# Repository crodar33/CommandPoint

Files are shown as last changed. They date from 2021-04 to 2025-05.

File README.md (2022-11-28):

# Code and shecme for control inverter
Scheme based on ESP8266 for pool data from BSM of the battery with **daly smart bms**
and provide battery data to **SOFAR HYBRID** inverter **HYD6000-ES**

They not compatible to each to other, so I need to make middle man for it work together.

In current implementation it can:

  * pull data from battery by RS485, UART
  * put data to the inverter by CAN and inner inverter protocol
  * show battery state by HTTP
  * show battery errors

Used ESP8266, MCP2515, MAX485 and nodeMCU, code writed on LUA
Build nodemcu with **I2C_MASTER_GPIO16_ENABLE** and without **I2C_MASTER_OLD_VERSION**
LUA_USE_MODULES_SOFTUART
LUA_USE_MODULES_STRUCT
LUA_USE_MODULES_U8G2

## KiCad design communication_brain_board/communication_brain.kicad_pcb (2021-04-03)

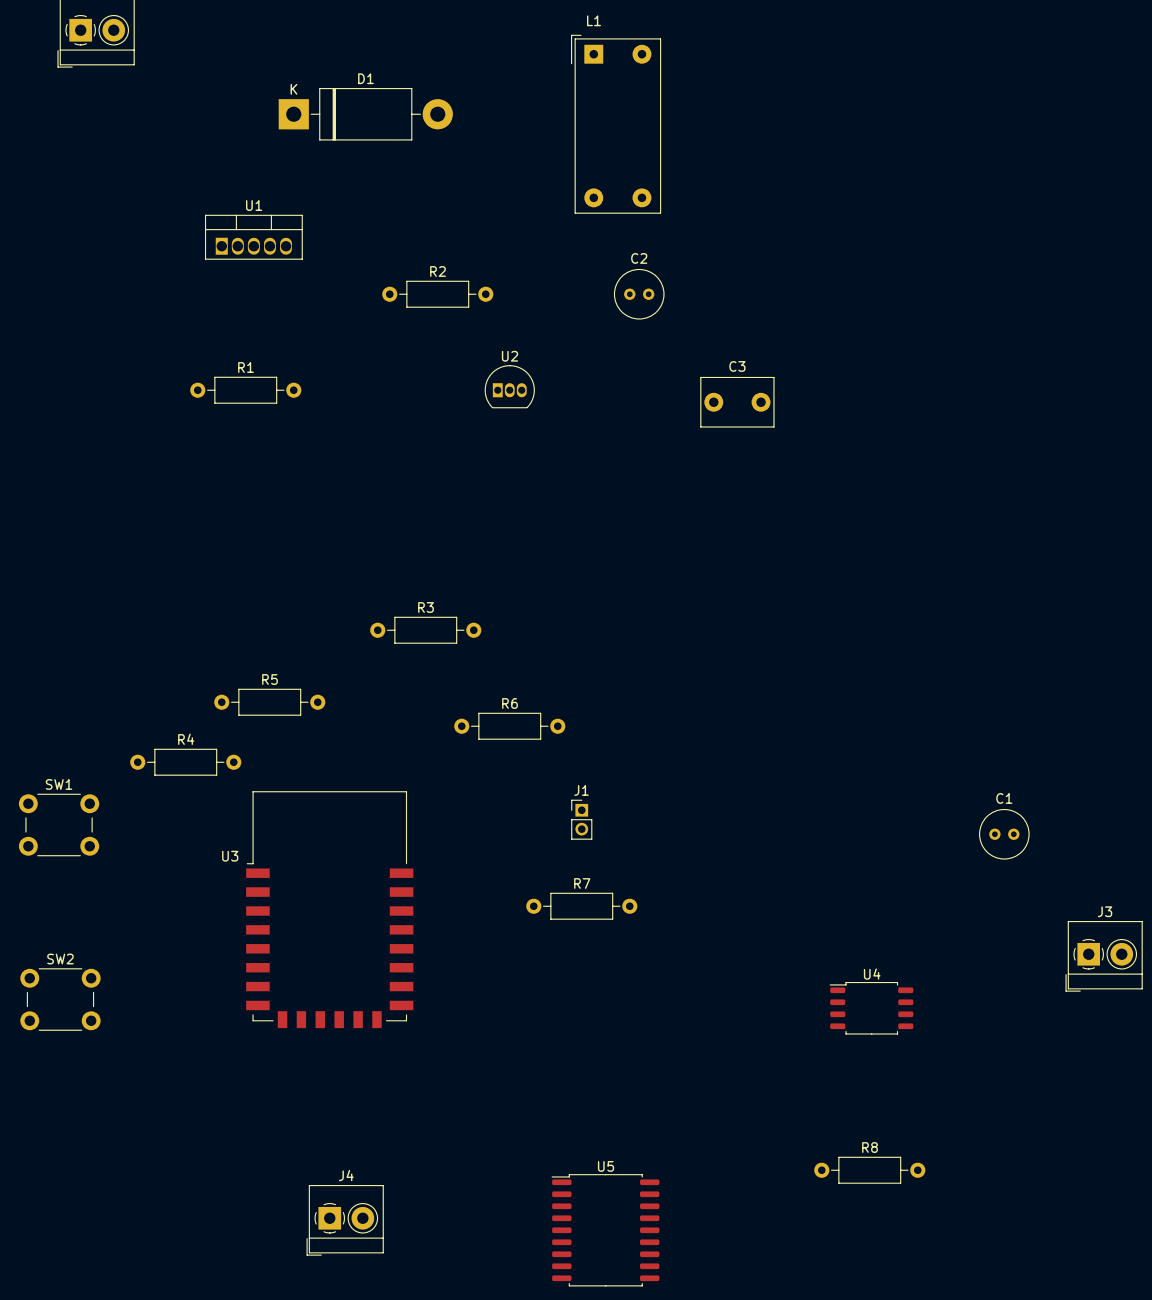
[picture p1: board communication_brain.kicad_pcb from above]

Board: 2 copper layers, 24 parts (0 on the bottom side), 23 nets, no tracks yet.

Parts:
C1: 100mF; C_Radial_D5.0mm_H5.0mm_P2.00mm
C2: 1000mF; C_Radial_D5.0mm_H5.0mm_P2.00mm
C3: 0.1mF; C_Disc_D7.5mm_W5.0mm_P5.00mm
D1: 1N5822; D_DO-201AD_P15.24mm_Horizontal
J1: UART; PinHeader_1x02_P2.00mm_Vertical
J2: Batt; TerminalBlock_4Ucon_1x02_P3.50mm_Horizontal
J3: RS485; TerminalBlock_4Ucon_1x02_P3.50mm_Horizontal
J4: CAN; TerminalBlock_4Ucon_1x02_P3.50mm_Horizontal
L1: 100mH; Choke_Schaffner_RN202-04-8.8x18.2mm
R1: 5.6k; R_Axial_DIN0207_L6.3mm_D2.5mm_P10.16mm_Horizontal
R2: 1.8k; R_Axial_DIN0207_L6.3mm_D2.5mm_P10.16mm_Horizontal
R3, R4, R5, R6, R7, R8: 10k; R_Axial_DIN0207_L6.3mm_D2.5mm_P10.16mm_Horizontal
SW1: Reset; SW_PUSH_6mm_H5mm
SW2: Programm; SW_PUSH_6mm_H5mm
U1: LM2576HVT-ADJ; TO-220-5_Vertical
U2: L78L33_TO92; TO-92_Inline
U3: ESP-12E
U4: MAX485E; SOIC-8_5.23x5.23mm_P1.27mm
U5: MCP2515-xSO; SOIC-18W_7.5x11.6mm_P1.27mm

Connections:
+3V3: C3.1, R3.1, R4.1, R5.1, R6.1, U2.1, U3.8, U4.8, U5.9, U5.18
+5V: C2.1, L1.2, R2.1, U2.3
+BATT: C1.1, J2.2, U1.1
-BATT: C1.2, C2.2, C3.2, D1.2, J2.1, R1.2, R7.2, R8.2, SW1.1, SW1.2, SW2.1, SW2.2, U1.3, U1.5, U2.2, U3.15, U4.5
/CS: U3.9, U5.16
/RXD: J1.1, U3.21
/SCK: U3.14, U5.13
/SI: U3.13, U5.14
/SO: U3.10, U5.15
/TXD: J1.2, U3.22
unnamed: D1.1, L1.1, U1.2
unnamed: J3.1, U4.7
unnamed: J3.2, U4.6
unnamed: J4.1, U5.2
unnamed: J4.2, U5.1
unnamed: R1.1, R2.2, U1.4
unnamed: R3.2, U3.3
unnamed: R4.2, U3.1
unnamed: R5.2, U3.18
unnamed: R6.2, U3.17, U4.1
unnamed: R7.1, U3.16
unnamed: R8.1, U3.6, U4.2, U4.3
unnamed: U3.7, U4.4

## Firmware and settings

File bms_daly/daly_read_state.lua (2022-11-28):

return function(battery, sUart, RW_pin)

    local callback = function(data)
        if not chechCRC(data) then
            print("bad CRC 0x98")
            print("Response: ", dataToString(data)) 
            return
        end
        if (struct.unpack("B", data, 2)~=battery.address) then
            return
        end
        battery.last_update = tmr.time()
        --print("Got state: ", dataToString(data)) 
        battery.state[0] = struct.unpack("b", data, 5+0)
        battery.state[1] = struct.unpack("b", data, 5+1)
        battery.state[2] = struct.unpack("b", data, 5+2)
        battery.state[3] = struct.unpack("b", data, 5+3)
        battery.state[4] = struct.unpack("b", data, 5+4)
        battery.state[5] = struct.unpack("b", data, 5+5)
        battery.state[6] = struct.unpack("b", data, 5+6)
        battery.state[7] = struct.unpack("b", data, 5+7)
    end
  
    print("request state")
    --request new data
    local sendData = struct.pack(">BBBBBBBBBBBBB", 0xA5, 0x40, 0x98, 0x08, 0, 0, 0, 0, 0, 0, 0, 0, 0x85)    
    --set callback on what we waiting
    --print("Requested: ", dataToString(sendData))
    sUart:on("data", 13, callback)
    --send data
    gpio.write(RW_pin, gpio.HIGH)
    sUart:write(sendData)
    gpio.write(RW_pin, gpio.LOW)

end

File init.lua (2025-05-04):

print("===========================================")
print("STARTING")
print("===========================================")
wifi.setmode(wifi.STATION)
local station_cfg= require("wifi_config")
wifi.sta.config(station_cfg)

function dataToString(data)
    local result = ''
    for i=1, #data do
        local val = struct.unpack(">B", data, i)
        result = result .. " 0X" .. string.format("%02X", val)
    end
    return result
end
 
ntpTime = 0
local modbus_proxy = nil
local wifiGotIpEvent = function(T)
    print("My IP: " .. T.IP)
    --watch for time
--[[
    timerNtp = tmr.create()
    timerNtp:register(10000, tmr.ALARM_AUTO, function()
        sntp.sync('192.168.42.1', 
            function(sec, usec, server, info) 
                print("ntp time " .. sec) 
                ntpTime = sec
            end,
            function()
                ntpTime = ntpTime + 10
            end
        )
    end)
    timerNtp:start()
]]
    --modbus_proxy = dofile("tcp_modbus.lua");
end

local wifiConnectEvent = function(T)
    print("Connection to AP("..T.SSID..") established!")
    print("Waiting for IP address...")
    if disconnect_ct ~= nil then disconnect_ct = nil end
end
wifiDisconnectEvent = function(T)
    if modbus_proxy ~= nil then
        modbus_proxy:close()
        modbus_proxy = nil
    end
    if T.reason == wifi.eventmon.reason.ASSOC_LEAVE then
        --the station has disassociated from a previously connected AP
        return
    end
    -- total_tries: how many times the station will attempt to connect to the AP. Should consider AP reboot duration.
    local total_tries = 75
    print("\nWiFi connection to AP("..T.SSID..") has failed!")

    --There are many possible disconnect reasons, the following iterates through
    --the list and returns the string corresponding to the disconnect reason.
    for key,val in pairs(wifi.eventmon.reason) do
        if val == T.reason then
            print("Disconnect reason: "..val.."("..key..")")
            --node.restart() 
            break
        end
    end

    if disconnect_ct == nil then
        disconnect_ct = 1
    else
        disconnect_ct = disconnect_ct + 1
    end
    if disconnect_ct < total_tries then
        print("Retrying connection...(attempt "..(disconnect_ct+1).." of "..total_tries..")")
    else
        wifi.sta.disconnect()
        print("Aborting connection to AP!")
        disconnect_ct = nil
        node.restart() 
    end
end
-- Register WiFi Station event callbacks
wifi.eventmon.register(wifi.eventmon.STA_CONNECTED, wifiConnectEvent)
wifi.eventmon.register(wifi.eventmon.STA_GOT_IP, wifiGotIpEvent)
wifi.eventmon.register(wifi.eventmon.STA_DISCONNECTED, wifiDisconnectEvent)

httpMuted = 0
node.setcpufreq(node.CPU160MHZ)

-- GPIO4-RX pin 4
-- GPIO2-TX pin 2
-- GPIO0-RW_flag pin 3
-- init soft urart
RW_pin = 3
RX_pin = 4
TX_pin = 2
print("init battary")
sUart = softuart.setup(115200, TX_pin, RX_pin)
gpio.mode(RW_pin, gpio.OUTPUT)

battery = dofile("battery.lc")(1, sUart, RW_pin)
battery:startPullData()
print("battery started pull")
--battery:stopPullData()
--stop inverter pull
--inverter = dofile("sofar_hyd6es.lua")(10, sUart, RW_pin)
--inverter:startPullData()
--pull battery state
--normal Mod
canStates = 1
inverterCmdMod = 0
inverterModTimer = 0
inverterMaxCurrent = 0
inveterChargeCorrection = 10
batTemp = 0
httpServer = dofile("http_server_core.lc")()
dofile("can_a1_test_init4.lua")

local timer3 = tmr.create()
timer3:register(600, tmr.ALARM_AUTO, function() if httpMuted==0 then dofile("can_a3_inform_invertor.lua") end end)
timer3:start()

dofile("display.lc")

local timer4 = tmr.create()
timer4:register(5000, tmr.ALARM_AUTO, function() dofile("broadcast_udp.lc") end)
timer4:start()

print("===========================================")
print("STARTED")
print("===========================================")

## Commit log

2021-03-29 optimizations and changes: - httpMuted flag for stop internals protocols - http post parser - changes in spi logic
2021-04-03 scheme added in git
    [communication_brain.kicad_pcb, communication_brain.sch]
2021-04-05 fixed scheme
    [communication_brain.sch]
2021-05-03 Schema update, little adjustments
    [communication_brain.sch]
2021-05-04 show temperature on state page, fixed battery state status show, added turbo charge - for "kicking" battery if it is desynchronizated
    [init.lua]
2021-09-20 reworked battarey communication for use daly smart bms
    [battery.lua, daly_read_cell.lua, daly_read_information.lua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]
2021-09-21 update shceme
    [communication_brain.sch]
2021-09-26 added support of display and little changes
    [communication_brain.sch]
2021-09-27 fixed current dispaly (we can't % negative values ...)
    [display.lua]
2021-11-24 added: - tcp modbus communication to battery - udb proadcast of battery stait - prepare for RS485 communication with invertor - updated readmy (modules needed for build) - stability
    [communication_brain.sch]
2022-11-28 added check of daly errors, added charge request in cell imbalance case
    [battery.lua, daly_read_state.lua, daly_read_status.lua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]
2022-12-03 added mod for longer charge (balancing)
2023-07-05 some fixes
    [communication_brain.kicad_sch]
2024-03-13 reworked to use Jiкоng bms, reworked work with spi-can library, reworked http server, smal fixes
    [communication_brain.kicad_sch]
2024-04-20 optimizations, fixes and other
    [battery.lua, jk_read_all.lua]
2024-04-20 fixed bug with discharge limitation
    [battery.lua]
2024-04-22 updated bms logc, updated web information and store
2025-05-04 reworked charge profile: now you can set max charge current on force charge + current control on dis-balanced charge
    [init.lua]
2026-06-23 possibility for discharge battery for fine calibration, small fixes
